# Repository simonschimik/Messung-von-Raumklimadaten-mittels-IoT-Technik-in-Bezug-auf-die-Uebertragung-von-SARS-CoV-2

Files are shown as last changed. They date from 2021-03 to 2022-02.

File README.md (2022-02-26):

# README
This repository contains the source code for the project referenced in my VWA "Messung von Raumklimadaten mittels IoT-Technik in Bezug auf die Übertragung von SARS-CoV-2". 

***Please read the following document in order to properly understand which files are supposed to be downloaded / edited if you want to recreate the project yourself.***

## Project objective
The target of this project is to use an Internet-Of-Things device, which measures and logs various indoor climate metrics, in order to provide evidence of the effectiveness of FFP2-mask mandates and mandatory ventilation in classrooms.

## Project components

 - [ESP32-DevKitC - Microcontroller](https://www.espressif.com/en/products/devkits/esp32-devkitc/overview)
 - [ST7735 1.8 Inch SPI TFT Display](https://www.az-delivery.de/products/1-8-zoll-spi-tft-display)
 - [GY-BME280 - Temperature, humidity and pressure sensor](https://www.az-delivery.de/products/gy-bme280)
 - [MH-Z19C - CO2-concentration sensor](https://www.reichelt.de/de/de/infrarot-co2-sensor-mh-z19c-pinleiste-rm-2-54-co2-mh-z19c-ph-p297320.html?r=1)
 - [novaPM SDS011 - PM10 and PM2.5 aerosol sensor ](https://www.reichelt.at/at/de/feinstaubsensor-nova-fitness-inkl-usb-adapter-sds011-p243264.html?r=1)

## Libraries used

 - [Adafruit BME280 Library](https://www.arduino.cc/reference/en/libraries/adafruit-bme280-library/)
 - [Adafruit BusIO](https://www.arduino.cc/reference/en/libraries/adafruit-busio/)
 - [Adafruit FONA Library](https://www.arduino.cc/reference/en/libraries/adafruit-fona-library/)
 - [Adafruit GFX Library](https://www.arduino.cc/reference/en/libraries/adafruit-gfx-library/)
 - [Adafruit MQTT Library](https://www.arduino.cc/reference/en/libraries/adafruit-mqtt-library/)
 - [Adafruit seesaw Library](https://www.arduino.cc/reference/en/libraries/adafruit-seesaw-library/)
 - [Adafruit SleepyDog Library](https://www.arduino.cc/reference/en/libraries/adafruit-sleepydog-library/)
 - [Adafruit ST7735 and ST7789 Library](https://www.arduino.cc/reference/en/libraries/adafruit-st7735-and-st7789-library/)
 - [Adafruit Unified Sensor](https://www.arduino.cc/reference/en/libraries/adafruit-unified-sensor/)
 - [AsyncElegantOTA](https://www.arduino.cc/reference/en/libraries/asyncelegantota/)
 - [AsyncTCP](https://github.com/me-no-dev/AsyncTCP)
 - [ESPAsyncWebServer](https://github.com/me-no-dev/ESPAsyncWebServer)
 - [EspSoftwareSerial](https://www.arduino.cc/reference/en/libraries/espsoftwareserial/)
 - [MH-Z19](https://www.arduino.cc/reference/en/libraries/mh-z19/)
 - [Nova Fitness Sds dust sensors library](https://www.arduino.cc/reference/en/libraries/nova-fitness-sds-dust-sensors-library/)

## How to download, edit and recreate

### What's included in the releases

 1. The needed source code files for either PlatformIO or the ArduinoIDE
 2. A Fritzing file showcasing the needed physical setup for the project
 3. **A "Reference.lnk" file, which opens the included docs, describing the entire functionality of the code**

### PlatformIO

 1. Download the corresponding project files from the [releases page](https://github.com/itssimsch/Messung-von-Raumklimadaten-mittels-IoT-Technik-in-Bezug-auf-die-Uebertragung-von-SARS-CoV-2/releases)
 2. Unzip the project files
 3. Open in PlatformIO and you should be good to go
 4. (A doxygen file which was used to generate the docs, but his has no real use)

### ArduinoIDE

 1. If not already done, **you need to install ESP32-Support in the Arduino IDE**. Please refer to this [guide](https://docs.espressif.com/projects/arduino-esp32/en/latest/installing.html) for detailed instructions
 2. Download the corresponding project files from the [releases page](https://github.com/itssimsch/Messung-von-Raumklimadaten-mittels-IoT-Technik-in-Bezug-auf-die-Uebertragung-von-SARS-CoV-2/releases)
 3. Unzip the downloaded archive - you should now have two folders: "libraries" and "Final-Arduino")
 4. Find your Arduino Sketchbook Folder in the Arduino IDE (File -> Preferences-> Sketchbook location). Open the specified path in your file explorer
 5. In said path, you should locate the Folder called "Arduino", containing the subdirectories "libraries" and "Sketchbooks" (and "tools", which we do not need to edit for this project)
 6. Move the folder "Final-Arduino" into the folder "Sketchbooks". 
 7. You can now open the "Final-Arduino.ino" file inside the "Final-Arduino" folder in the Arduino IDE
 8. Lastly, you need to install the needed libraries. There are two options for that:
		
	 - **The easiest way would** be to copy all folders from the "libraries" folder that I provided in the release (the libraries folder you extracted earlier) into the "libraries" folder in your Arduino IDE Sketchbook location.

	 - Manually download the libraries: Download all libraries from the list above using the library manager inside the Arduino IDE. **NOTE: There are two libraries that cannot be downloaded using the library manager. For "AsyncTCP" and "ESPAsyncWebServer" you need to visit the linked GitHub repositories, download the project files and extract them into the libraries folder.** 

 9. No matter which of the two methods you use, you should end up with a folder structure (inside the Arduino folder) somewhat similar to this:
```
    ├───libraries
    │   ├───Adafruit_BME280_Library
    │   ├───Adafruit_BusIO
    │   ├───Adafruit_FONA_Library
    │   ├───Adafruit_GFX_Library
    │   ├───Adafruit_MQTT_Library-2.1.0
    │   ├───Adafruit_seesaw_Library
    │   ├───Adafruit_SleepyDog_Library
    │   ├───Adafruit_ST7735_and_ST7789_Library
    │   ├───Adafruit_Unified_Sensor
    │   ├───AsyncElegantOTA
    │   ├───AsyncTCP-master
    │   ├───ESPAsyncWebServer-master
    │   ├───EspSoftwareSerial
    │   ├───MH-Z19
    │   └───Nova_Fitness_Sds_dust_sensors_library
    ├───Sketchbooks
    │   └───Final-Arduino
    └───tools

```

**If you have any problems, please create an issue at my GitHub repository!**

## Source code - Folders (only needed if you download the entire repos.)
### ESP8266-Archive
Contains archived code from an early version of the project, in which the smaller microcontroller ESP8266 was used. This project was archived because said microcontroller didn't provide enough GPIOs to support all sensors. Hence, the project was continued with the ESP32 microcontroller.

### Components

Contains short code snippets that showcase the general principle of how communication with the respective sensors works. Moreover, it contains Fritzing files that display the used wiring.

### Ver1.0

Includes the source code for the first combination of all sensors. Functionality was very limited and bugged. **This version was still developed using the Arduino IDE**

### Ver2.0
Contains all project files from the second project version. This version incorporated most of the desired functionalities and was working without major problems. There are only minor differences to the final version. **As opposed to version 1.0, the development of version 2.0 was carried out using [PlatformIO](https://platformio.org/) and Visual Studio Code.**

### Final-PIO
Contains all project files, that were used in the final setup of the project. **This folder still contains all source code in the PlatformIO format.**
 
 ### Final-Arduino
 Contains all project files, that were used in the final setup of the project. **This folder contains the project files of Final-PIO, but I converted them, so they can be used in the Arduino IDE.**

## License
MIT License

Copyright (c) 2022 Schimik Simon

Permission is hereby granted, free of charge, to any person obtaining a copy
of this software and associated documentation files (the "Software"), to deal
in the Software without restriction, including without limitation the rights
to use, copy, modify, merge, publish, distribute, sublicense, and/or sell
copies of the Software, and to permit persons to whom the Software is
furnished to do so, subject to the following conditions:

The above copyright notice and this permission notice shall be included in all
copies or substantial portions of the Software.

THE SOFTWARE IS PROVIDED "AS IS", WITHOUT WARRANTY OF ANY KIND, EXPRESS OR
IMPLIED, INCLUDING BUT NOT LIMITED TO THE WARRANTIES OF MERCHANTABILITY,
FITNESS FOR A PARTICULAR PURPOSE AND NONINFRINGEMENT. IN NO EVENT SHALL THE
AUTHORS OR COPYRIGHT HOLDERS BE LIABLE FOR ANY CLAIM, DAMAGES OR OTHER
LIABILITY, WHETHER IN AN ACTION OF CONTRACT, TORT OR OTHERWISE, ARISING FROM,
OUT OF OR IN CONNECTION WITH THE SOFTWARE OR THE USE OR OTHER DEALINGS IN THE
SOFTWARE.

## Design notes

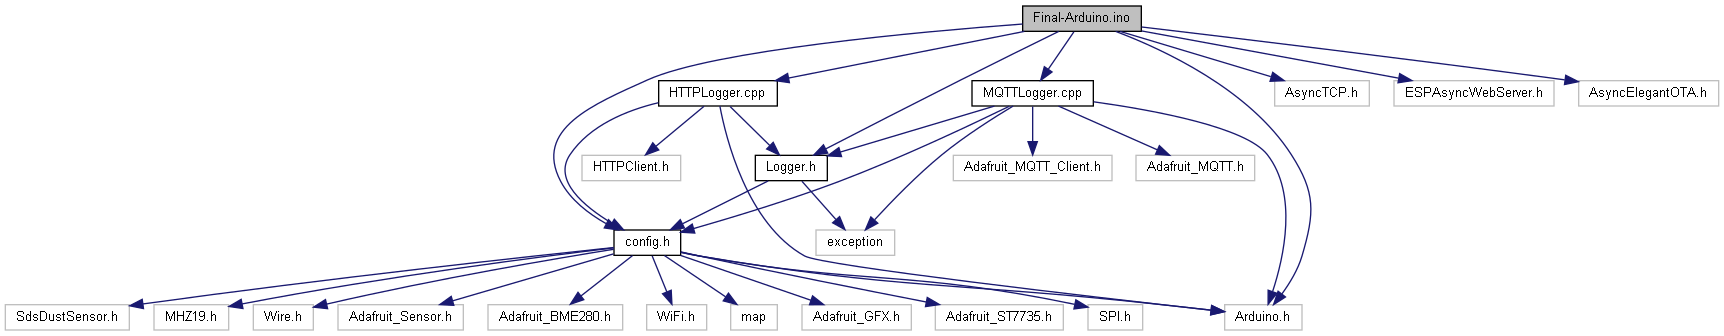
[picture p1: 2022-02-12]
Final-Arduino/doc/html/db/d1d/_final-_arduino_8ino__incl.png

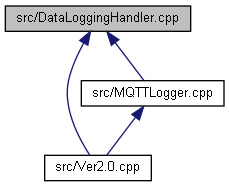
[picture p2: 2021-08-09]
Final-Arduino/doc/html/d6/d10/_data_logging_handler_8cpp__dep__incl.png

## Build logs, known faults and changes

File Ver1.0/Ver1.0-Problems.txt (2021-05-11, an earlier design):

- no proper serial debug
- pm levels without precision on tft
- temp not accurate?
- no preheating
- no faulty sensor readings prevention
- sloppy / rushed / functional code
- only makeshift debug/ota webserver interface
- wiring could be improved
- documentation?
- code needs to be abstracted properly
- SDS011 always running

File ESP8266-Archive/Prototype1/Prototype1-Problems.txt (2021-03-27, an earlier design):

- PM levels not precise on display
- Serial communication not possible since tx and rx pins are used for sds011
- Display flickering
- Faulty sensor outputs not handled

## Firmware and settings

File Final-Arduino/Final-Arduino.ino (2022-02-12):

/**
 * @file Final-Arduino.ino
 * @author Simon Schimik
 * @version 3.0
 */

#include "Arduino.h" 
#include "config.h"
#include "Logger.h"
#include "MQTTLogger.cpp"
#include "HTTPLogger.cpp"

#include <AsyncTCP.h>
#include <ESPAsyncWebServer.h>
#include <AsyncElegantOTA.h>

AsyncWebServer server(80); 
Adafruit_ST7735 tft(TFT_CS, TFT_DC, TFT_RST);
SdsDustSensor sds(SDS_RX, SDS_TX);
MHZ19 myMHZ19;                                            
HardwareSerial mhSerial(1); // Use UART channel 1  
Adafruit_BME280 bme;
Logger* logger;
uint32_t timer;

/**
 * std::map containing sensor values.
 * 
 * std::map containing sensor values, the keys for the respective sensor values are reused as feed names for MQTTLogger.
 */
std::map<const char*, double>* sensorData  = new std::map<const char*, double>{
  {"temperature", 0.0},
  {"humidity", 0.0},
  {"pressure", 0.0},
  {"pm10", 0.0},
  {"pm25", 0.0},
  {"CO2", 0.0}
};

/**
 * Initialises OTA-Server.
 * 
 * Initialises an asynchronous webserver and starts ElegentOTA functionality.
 */
void initElegentOTA()
{
  Serial.println("Initialising OTA-server!");

  server.on("/", HTTP_GET, [](AsyncWebServerRequest *request) {
    request->send(200, "text/plain", "OTA-Server active!");
  });
  AsyncElegantOTA.begin(&server);
  server.begin();
  Serial.println("OTA-server server started");
}


/**
 * Connects to WiFi.
 * 
 * Initialises a WiFi connection with the specified credentials. 
 * Function will not terminate until WiFi connection is successfull.
 */
void connectWifi()
{
  Serial.print("Connecting to WiFi " + String(SSID));
  WiFi.mode(WIFI_STA);
  WiFi.begin(SSID, PASS);
  uint8_t reconnectCount = 0;

  // Wait for connection
  while (WiFi.status() != WL_CONNECTED) {
    delay(1000);
    if(++reconnectCount > WIFI_CONNECT_LIMIT) ESP.restart();
  }
  Serial.println("\nWiFi-connection successfull!");
  Serial.print("IP address: ");
  Serial.println(WiFi.localIP().toString());
}

/**
 * Draws centered text on display.
 * 
 * @param text The text to be printed.
 * @param x Width of the screen in which the text is supposed to be centered (f.e. <b> x = tft.width() </b> centers the text on the entire display, <b> x = tft.width()  / 2 </b>  only on the left half of the display).
 * @param y Y position of the centered text on the display.
 */
void drawCenteredText(String text, uint8_t x, uint8_t y)
{
  int16_t x1, y1;
  uint16_t w, h;
  tft.getTextBounds(text, x, y, &x1, &y1, &w, &h);
  tft.setCursor((x - w) / 2, y);
  tft.print(text);
}

/**
 * Returns a color based on the parameter pm10.
 * 
 * Returns a color for better visualisation on the display of the pm10 value.
 * @param pm10 The pm10 value.
 * @return Returns a 16-bit hexadecimal representation of the corrosponding color.
 */
uint16_t getPm10Color(double pm10)
{
  if(pm10 <= 50) return ST7735_CYAN;
  else if(pm10 <= 100) return ST7735_GREEN;
  else if(pm10 <= 250) return ST7735_YELLOW;
  else if(pm10 <= 350) return ST7735_ORANGE;
  else if(pm10 <= 430) return ST7735_RED;
  else return ST7735_PURPLE;
}

/**
 * Returns a color based on the parameter pm25.
 * 
 * Returns a color for better visualisation on the display of the pm2.5 value.
 * @param pm25 The pm2.5 value.
 * @return Returns a 16-bit hexadecimal representation of the corrosponding color.
 */
uint16_t getPm25Color(double pm25)
{
  if(pm25 <= 30) return ST7735_CYAN;
  else if(pm25 <= 60) return ST7735_GREEN;
  else if(pm25 <= 90) return ST7735_YELLOW;
  else if(pm25 <= 120) return ST7735_ORANGE;
  else if(pm25 <= 250) return ST7735_RED;
  else return ST7735_PURPLE;
}

/**
 * Returns a color based on the parameter co2.
 * 
 * Returns a color for better visualisation on the display of the co2 value.
 * @param co2 The co2 value.
 * @return Returns a 16-bit hexadecimal representation of the corrosponding color.
 */
uint16_t getCO2Color(double co2)
{
  if(co2 <= 650) return ST7735_CYAN;
  else if(co2 <= 950) return ST7735_GREEN;
  else if(co2 <= 1250) return ST7735_YELLOW;
  else if(co2 <= 1500) return ST7735_ORANGE;
  else if(co2 <= 1850) return ST7735_RED;
  else return ST7735_PURPLE;
}

/**
 * Prints the regular UI and sensor values.
 * 
 * Prints the current sensor values stores in field std::map<const char*, double>* sensorData.
 */
void printRegularDisplay()
{
  // Clear screen
  tft.fillScreen(ST7735_BLACK);
  
  // Draw outlines
  tft.drawLine(0, 0, tft.width(), 0, ST7735_WHITE);
  tft.drawLine(0, 0, 0, tft.height(), ST7735_WHITE);
  tft.drawLine(0, tft.height()-1, tft.width()-1, tft.height()-1, ST7735_WHITE);
  tft.drawLine(tft.width()-1, 0, tft.width()-1, tft.height()-1, ST7735_WHITE);

  // Draw sections
  tft.drawLine(0, tft.height()*5/12, tft.width(), tft.height()*5/12, ST7735_WHITE);
  tft.drawLine(0, tft.height()*2/3, tft.width(), tft.height()*2/3, ST7735_WHITE);
  tft.drawLine(tft.width()/2, tft.height()*2/3, tft.width()/2, tft.height(), ST7735_WHITE);

  // Draw headers
  tft.setTextSize(1);
  tft.setTextColor(ST7735_WHITE);
  drawCenteredText("Temperature", tft.width(), 5);
  drawCenteredText("Humidity", tft.width(), 25);
  drawCenteredText("Pressure", tft.width(), 45);
  drawCenteredText("CO2-Concentration", tft.width(), tft.height()*5/12 + 2);
  drawCenteredText("ppm", tft.width(), tft.height()*5/12 + 30);
  drawCenteredText("PM10", tft.width()/2+2, tft.height()*2/3+2);
  drawCenteredText("PM2.5", tft.width()*3/2+2, tft.height()*2/3+2);
  drawCenteredText("um_g/m^3", tft.width() / 2, tft.height()*2/3+43);
  drawCenteredText("um_g/m^3", tft.width() * 3/2, tft.height()*2/3+43);

  // Draw sensor values
  tft.setTextSize(1);
  tft.setTextColor(ST7735_BLUE);
  drawCenteredText(String(sensorData->at("temperature")) + " C", tft.width(), 15);
  drawCenteredText(String(sensorData->at("humidity")) + " %", tft.width(), 35);
  drawCenteredText(String(sensorData->at("pressure")) + " hPa", tft.width(), 55);

  tft.setTextSize(2);
  tft.setTextColor(getCO2Color(sensorData->at("CO2")));
  drawCenteredText(String((int)sensorData->at("CO2")), tft.width(), tft.height()*5/12 + 13);
  tft.setTextColor(getPm10Color(sensorData->at("pm10")));
  drawCenteredText(String(sensorData->at("pm10")), tft.width() / 2, tft.height()*2/3+17);
  tft.setTextColor(getPm25Color(sensorData->at("pm25")));
  drawCenteredText(String(sensorData->at("pm25")), tft.width() * 3/2, tft.height()*2/3+17);
}

/**
 * Prints an error display.
 * 
 * Prints every string in the passed array into a new line on the tft.
 * @param data std::array of 8 string to be printed into seperate lines.
 * @param primaryColor text-color.
 */
void printDebugDisplay(std::array<String, 8> data, uint16_t primaryColor)
{
  tft.fillScreen(ST7735_BLACK);
  tft.setTextSize(1);
  tft.setTextColor(primaryColor);
  for(uint8_t i = 0; i < 8; i++)
  {
    drawCenteredText(data[i], tft.width(), 5 + i*20);
  }
}

/**
 * Reads sensor values.
 * 
 * Reads sensors and assigns the retrieved values to the corresponding pairs in std::map<const char*.
 */
void readSensors()
{
  PmResult sds_results = sds.queryPm();
  if (sds_results.isOk()){
    sensorData->at("pm25") = sds_results.pm25;
    sensorData->at("pm10") = sds_results.pm10;
  } else {
    sensorData->at("pm25") = -1;
    sensorData->at("pm10") = -1;
  }
  
  sensorData->at("CO2") = myMHZ19.getCO2();
  sensorData->at("temperature") = bme.readTemperature();
  sensorData->at("humidity") = bme.readHumidity();
  sensorData->at("pressure") = bme.readPressure() / 100.0;
  
}

/**
 * Initialises the SDS011 sensor.
 * 
 * Initialises the SDS011 sensor, retrieves firmware and preheats the sensor .
 * 
 * @return true if initialisation was successfull.
 * @return false if communication with sensor failed at any point during initialisation.
 */
bool initSDS()
{
  printDebugDisplay({"Initialising SDS011"}, ST7735_WHITE);
  sds.begin();

  if(!sds.queryFirmwareVersion().isOk() || !sds.setQueryReportingMode().isOk() || !sds.wakeup().isOk())
  {
    printDebugDisplay({"Initialising SDS011", "Initialisation failed", "Restarting in 10s"}, ST7735_RED);
    delay(10000);
    return false;
  }

  PmResult last = sds.queryPm();
  PmResult curr = sds.queryPm();
  if(!last.isOk() || !curr.isOk())
  {
    printDebugDisplay({"Initialising SDS011", "Failed to retrieve values", "Restarting in 10s"}, ST7735_RED);
    delay(10000);
    return false;
  }

  do{
    last = curr;
    delay(1000);
    curr = sds.queryPm();
    printDebugDisplay({"Initialising SDS011", "Firmware: " + sds.queryFirmwareVersion().toString().substring(35), "Preheating...", "PM2.5:" + String(curr.pm25), 
                        "PM10:" + String(curr.pm10), "Threshold: " + String(SDS_PREHEAT_THRESHOLD)},  ST7735_WHITE);
  }while(last.pm10 - curr.pm10 > SDS_PREHEAT_THRESHOLD || last.pm25 - curr.pm25 > SDS_PREHEAT_THRESHOLD);
  
  return true;
}

/**
 * Initialises the MHZ-19C sensor.
 * 
 * Initialises the MHZ-19C sensor and preheats the sensor .
 * 
 * @return true if initialisation was successfull.
 * @return false if communication with sensor failed at any point during initialisation.
 */
bool initMHZ()
{
  mhSerial.begin(9600, SERIAL_8N1, 32, 33);                               
  myMHZ19.begin(mhSerial);                                
  myMHZ19.autoCalibration(false);

  uint16_t curr = 0;
  uint16_t last = 0;
  uint8_t counter = 0;
  do{
    last = curr;
    delay(10000);
    curr = myMHZ19.getCO2();
    printDebugDisplay({"Initialising MH-Z19C", "Preheating", "CO2: " + String(curr), "Threshold:" + String(MH_PREHEAT_THRESHOLD)}, ST7735_WHITE);

    if(++counter > 6) // If still not working after 60 seconds, probably faulty connection
    {
      printDebugDisplay({"Initialising MH-Z19C", "Failed to retrieve ", "sensor values!", "Restarting in 10s"}, ST7735_RED);
      delay(10000);
      return false;
    }
  }while(last - curr > MH_PREHEAT_THRESHOLD || curr == 0 || last == 0);
  
  return true;
}

/**
 * Predefined setup-function.
 * 
 * Is called once in the beginning of runtime.
 */
void setup() 
{
  Serial.begin(9600);
  // Init TFT
  tft.initR(INITR_BLACKTAB); 
  tft.fillScreen(ST7735_BLACK);
  tft.setTextSize(1);

  if(!initSDS()) ESP.restart();
  if(!initMHZ()) ESP.restart();

  // Init BME280
  if(!bme.begin(0x76))
  {
    printDebugDisplay({"Initialising BME280", "Failed to communicate with BME280", "Restarting in 10s"}, ST7735_RED);
    delay(10000);
    ESP.restart();
  }
  // Setup WiFi-connection
  printDebugDisplay({"Connecting to WiFi", "SSID: " + String(SSID)}, ST7735_WHITE);
  connectWifi();

  // Setup Server
  printDebugDisplay({"Initialising OTA-Server", "SSID: " + String(SSID), "IP: " + WiFi.localIP().toString(), "Host: " + String(WiFi.getHostname()), 
                     "WiFi connected: " + String(WiFi.isConnected())}, ST7735_WHITE);
  initElegentOTA();
  
  // Init logger
  printDebugDisplay({"Initialising logger!"}, ST7735_WHITE);
  logger = new HTTPLogger();
  timer = 0;
}

/**
 * Predefined loop-function.
 * 
 * Is called repeatedly during runtime.
 */
void loop()
{
  if(timer == LOOPDELAY)
  {
    timer = 0;
    try
    {
      readSensors();
      logger->log(sensorData);
      printRegularDisplay();
    }catch(LoggerException& e)
    {
      printDebugDisplay({"A Logger Exception", "occured!" ,"IP: " + WiFi.localIP().toString(), "Host: " + String(WiFi.getHostname()), 
                          "WiFi connected: " + String(WiFi.isConnected()), "Reset in " + String(LOOPDELAY/1000) + "s", String(e.error), e.what()}, ST7735_RED);
      delay(LOOPDELAY);
      ESP.restart();
    }catch(WifiNotConnectedException& e) 
    {
      printDebugDisplay({"WiFi connection lost!", "Reconnecting..."}, ST7735_RED);
      connectWifi();
    }
  }

  /**
   * The AsyncElegantOTA.loop() statement must be called repeatedly throughout the loop function. Pausing the loop function directly by delay(LOOPDELAY)
   * would cause unpredictable errors from the OTA-service, since the AsyncElegantOTA.loop() statement wouldn't be called for extended periods of time.
   * Therefore, the loop is only paused for 1ms, and instead the counter-var 'timer' is introduced.
   */

  AsyncElegantOTA.loop();
  delay(1); timer++;
}

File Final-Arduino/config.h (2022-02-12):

#pragma once
/**
 * @file config.h
 * @author Simon Schimik
 * @version 3.0
 */

// Arduino Core-libraries
#include "Arduino.h"

// C++-Standard-libraries
#include <map>

// TFT-Libraries
#include <Adafruit_GFX.h>    // Core graphics library
#include <Adafruit_ST7735.h> // Hardware-specific library for ST7735
#include <SPI.h>

// SDS011-Library
#include <SdsDustSensor.h>

// MH-Z19C-Library
#include "MHZ19.h"     

// BME280-Libraries
#include <Wire.h>
#include <Adafruit_Sensor.h>
#include <Adafruit_BME280.h>

// Connectivity
#include <WiFi.h>

// TFT-Pins
#define TFT_CS 5 
#define TFT_RST 17                                
#define TFT_DC 16 

// SDS011-Pins
#define SDS_RX 25
#define SDS_TX 26

// MH-Z19C-Pins
#define MH_TX 32
#define MH_RX 33

#define SSID ""
#define PASS ""

// MQTTLogger
#define AIOSERVER "0.0.0.0"
#define AIOSERVERPORT 1883
#define AIOUSERNAME ""
#define AIOKEY ""
#define LOOPDELAY 15000

// HTTPLogger
#define HTTPSERVER ""

/** Defines limit for the WiFi-reconnect-count until ESP reset.*/
#define WIFI_CONNECT_LIMIT 30

/** Defines limit for the MQTT-reconnect-count until ESP reset.*/
#define MQTT_CONNECT_LIMIT 5

/**
 * Defines a threshold for SDS011-sensor values variation during preheating.
 * 
 * SDS011-Preheating will only succeed once two sensor readings taken after another do not vary by more than this amount.
 */
#define SDS_PREHEAT_THRESHOLD 0.5

/**
 * Defines a threshold for MHZ-19C-sensor values variation during preheating.
 * 
 * MHZ-19C-Preheating will only succeed once two sensor readings taken after another do not vary by more than this amount.
 */
#define MH_PREHEAT_THRESHOLD 10

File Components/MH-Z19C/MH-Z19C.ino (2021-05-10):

#include "MHZ19.h"                                        

#define RX_PIN 33                                          // Rx pin which the MHZ19 Tx pin is attached to
#define TX_PIN 32                                          // Tx pin which the MHZ19 Rx pin is attached to
#define BAUDRATE 9600                                      

MHZ19 myMHZ19;                                            
HardwareSerial mySerial(1); // Use UART channel 1  

void setup() {
  Serial.begin(9600);                                     
  mySerial.begin(BAUDRATE, SERIAL_8N1, 32, 33);                               
  myMHZ19.begin(mySerial);                                
  myMHZ19.autoCalibration(false); 
  Serial.println("Preheating sensor!");
  //delay(120000);

}

void loop() {
  int CO2; 
  CO2 = myMHZ19.getCO2();
  Serial.print("CO2 (ppm): ");                      
  Serial.println(CO2);
  
  delay(2000);                                      
}

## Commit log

2021-03-24 added fritzing file for bme280-test
    [BME280-Wiring.fzz]
2021-03-25 added fritzing for tft
    [TFT-Wiring.fzz]
2021-03-26 finished dummy tft design, edited tft fritzing, added mh-z19c base code + fritzing
    [MH-Z19C.fzz, TFT-Wiring.fzz]
2021-03-26 added base code and fritzing for sds011, updated past fritzings, added fritzing for prototype1
    [BME280-Wiring.fzz, MH-Z19C.fzz, Prototype1.fzz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]
2021-03-27 archived all work using ESP8266, project will resume using ESP32
    [BME280-Wiring.fzz, MH-Z19C.fzz, Prototype1-LAPTOP-SIMSCH.fzz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]
2021-05-10 removed past commits because of sensitive data, finished Ver1.0
    [BME280-Wiring.fzz, MH-Z19C.fzz, SDS011.fzz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]
2021-05-11 started working on Ver2.0, abstracted code, began doc
    [Ver2.0.fzz]
2021-05-29 Move to Platform.io + Improvements
    Successfully moved to platform.io, moved import preproc defs to config.h, updated both the main sketch + MQTTLogger to use std::map instead of a list of doubles, implemented exception handling for MQ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
    [Ver2.0.fzz]
2021-06-06 Implemented workaround for publish-bug
    [Ver2.0.cpp]
2021-06-06 Implemented reset in case of connections repeatedly failing, minor rewrites
    [Ver2.0.cpp, config.h]
2022-02-12 Final Commit
    Upload of the final version used + arduino version for release, minor changes basically everywhere
    [Final.fzz, SDS011.fzz, TFT-Wiring.fzz]
